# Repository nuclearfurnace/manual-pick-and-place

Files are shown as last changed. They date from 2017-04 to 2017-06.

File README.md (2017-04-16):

# manual-pick-and-place
A manual pick-and-place platform for DIY electronics, with an upgrade path.

## the goal
We want a solid pick and place table for manually placing components on prototypes and small runs.

DIY pick and place machines have successfully used off-the-shelf aluminum extrusions and linear guides/bearings to build rigid platforms that are suitable for precise work, even down to 0402 components.  There is a wide gulf, however, between manual set-ups and automatic/CNC machines.

Most manual setups involve tweezers or vacuum pens, which open up issues like gripping parts, dropping parts, dragging your hand across the board, etc. Even "advanced" manual setups are usually cobbled together, with parts you buy from a Home Depot or Lowes.

Our goal is to build a manual pick and place machine that has all the benefits of a CNC-enabled design -- modular, rigid, precise -- while staying simple enough to be usable by hand.  By using the same basic components as its CNC-enabled brethren, like aluminum extrusions and linear bearings, we can design a pick and place table that is capable of being upgraded to full auto in the future.

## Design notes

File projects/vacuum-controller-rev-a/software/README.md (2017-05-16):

Vacuum Controller software
--------------------------

This software powers the vacuum controller, controlling when the valves are opened/closed and for how long.  It's powered by an ATtiny85, so it's written in ANSI C targetting the Atmel AVR libraries.

We use simavr to simulate the firmware so we can write it without hardware in hand, and also more easily pin down behaviors without needing to trace an entire board.

how to use
----------

You should be able to run `make clean run` from this directory and have it just work.

You may or may not need to do something like:

    brew tap osx-cross/avr
    brew install --HEAD simavr

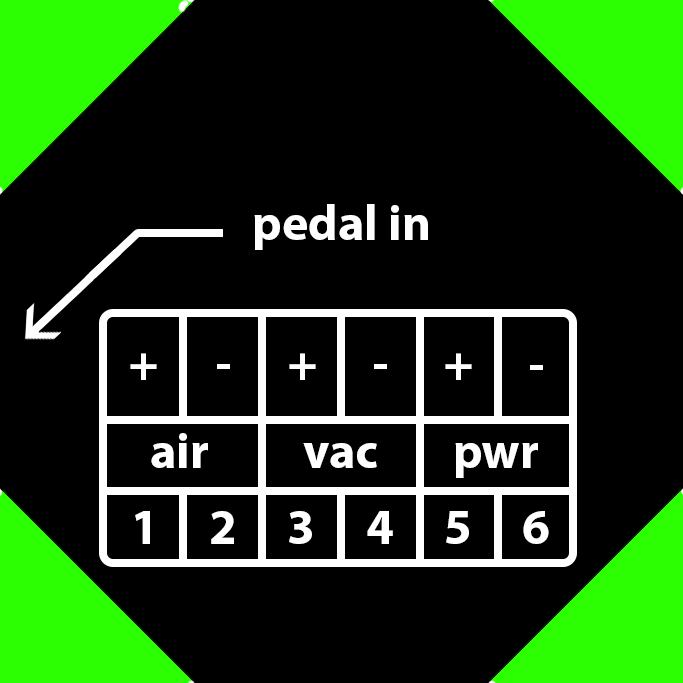
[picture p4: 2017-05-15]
projects/vacuum-controller-rev-a/graphics/vacuum-controller-panel.tif

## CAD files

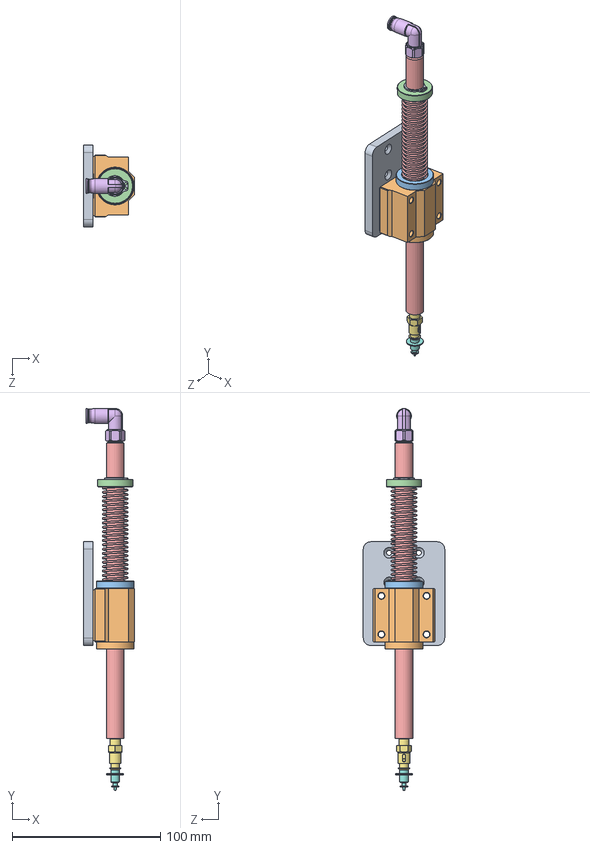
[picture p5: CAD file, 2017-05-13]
place-head-subassembly.SLDASM
34.3 x 257.8 x 55.0 mm
z-axis-bracket
LHBB12-1_b
LMU-N12
LH-RRING-C-INT-S-21 x 2
5964K110_HARDENED PRECISION TUBULAR METRIC SHAFT
RTCNL4-M5
cp40-nozzle-holder
cp40-test-nozzle
90967A165_STAINLESS STEEL EXTERNAL RETAINING RING x 2
nozzle-shaft-bottom-end-stop
nozzle-shaft-bottom-spring-holder
nozzle-shaft-top-spring-holder
9657K124_STEEL COMPRESSION SPRING

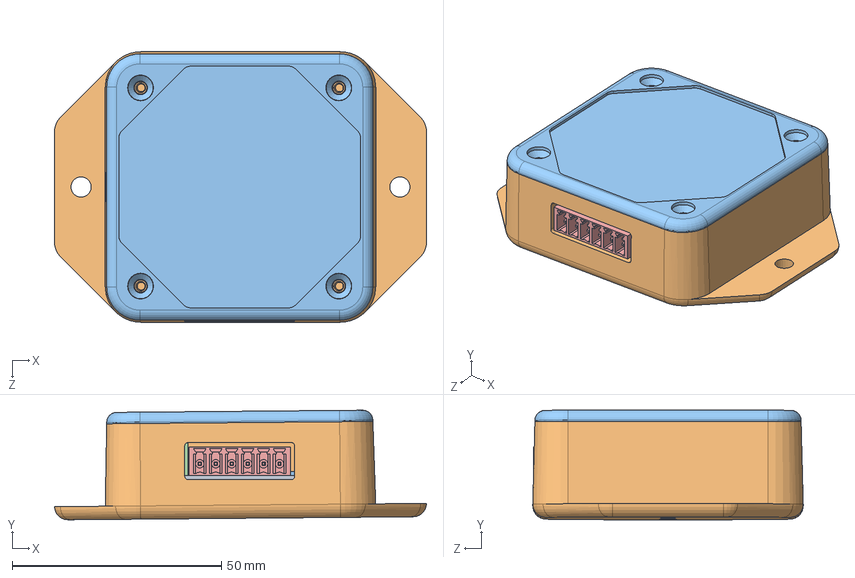
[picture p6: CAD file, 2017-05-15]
projects/vacuum-controller-rev-a/enclosure/vacuum-controller.SLDASM
88.9 x 26.2 x 64.6 mm
vacuumcontrollerreva
SOD323R_PMEG1020EA
SMA_13_6V
MJ-3536N
RPDSOG5DBV_LP5907MFX2_8
EIAJSOIC8_ATTINY8520SU
SOT457_SZNUD3124
RPDSOG5DCK_SN74AHC1G14DCK
LP-11F-bottom
LP-11F-cover

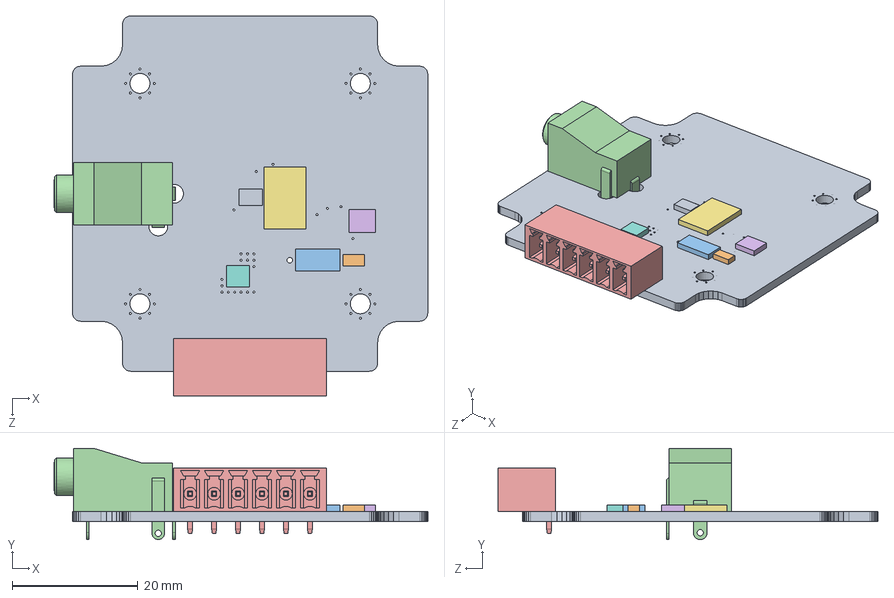
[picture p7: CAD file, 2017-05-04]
projects/vacuum-controller-rev-a/enclosure/components/vacuum-controller-board.SLDASM
59.4 x 14.5 x 60.4 mm
vacuumcontrollerreva
SOD323R_PMEG1020EA
SMA_13_6V
MJ-3536N
RPDSOG5DBV_LP5907MFX2_8
EIAJSOIC8_ATTINY8520SU
SOT457_SZNUD3124
RPDSOG5DCK_SN74AHC1G14DCK

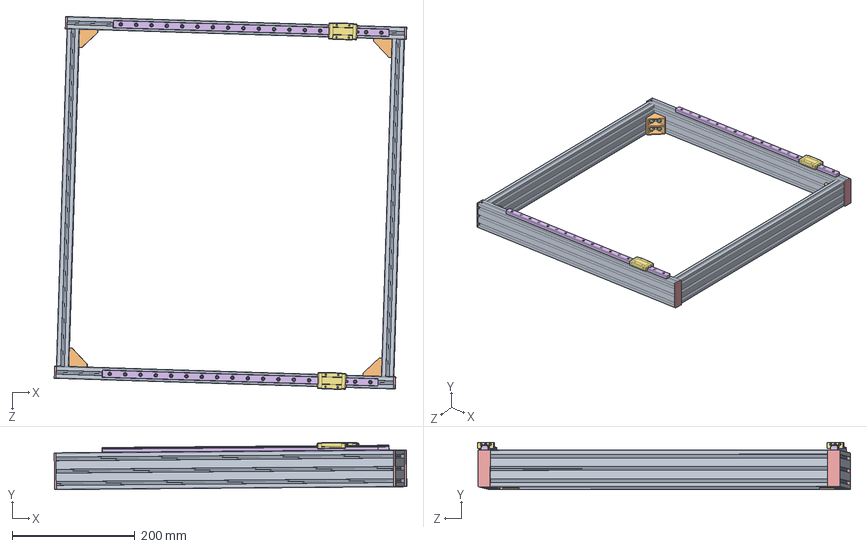
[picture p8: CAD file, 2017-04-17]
base-frame.SLDASM
574.8 x 77.0 x 608.0 mm
HFS5-2060-550 x 4
HBLFSN5h5 x 8
HNTT5-5 x 16
91292A124_TYPE 18-8 SS SOCKET HEAD CAP SCREW x 16
HFC5-2060-B x 4
MGN_12_H_RAIL x 2
MGN_12_H_CARRAGE x 2
HNTT5-3 x 20
91292A112_TYPE 18-8 SS SOCKET HEAD CAP SCREW x 20

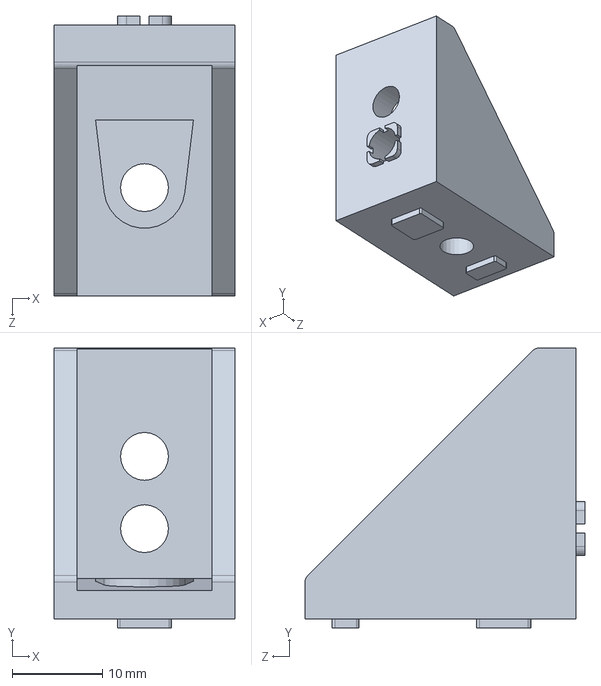
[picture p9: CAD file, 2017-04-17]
components/HBLFSN5.sldasm
20.0 x 31.0 x 31.0 mm

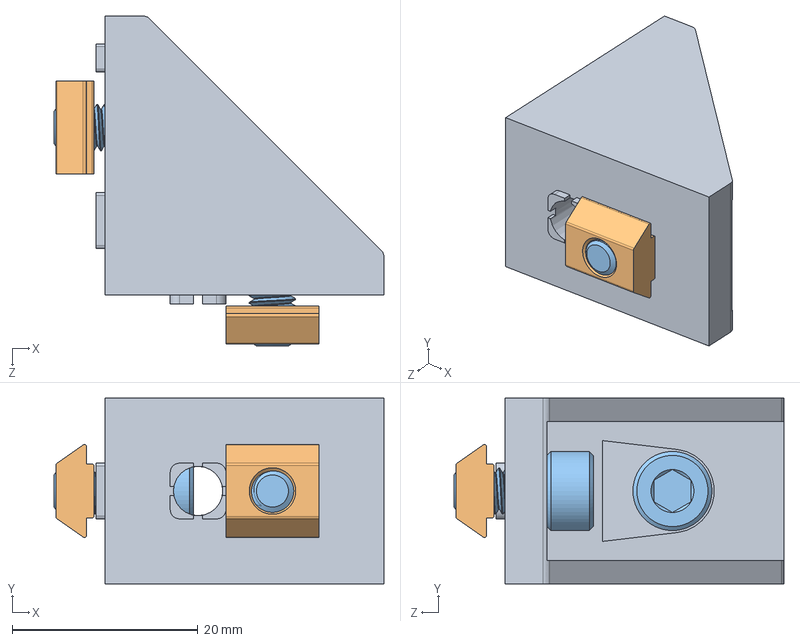
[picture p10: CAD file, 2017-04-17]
corner-bracket-w-hardware.SLDASM
35.5 x 20.0 x 35.5 mm
HBLFSN5h5
HNTT5-5 x 2
91292A124_TYPE 18-8 SS SOCKET HEAD CAP SCREW x 2

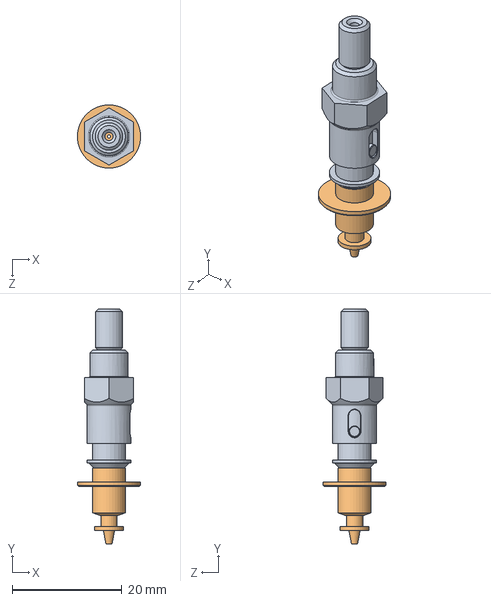
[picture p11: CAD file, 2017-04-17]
nozzle-assembly.SLDASM
11.5 x 42.8 x 11.5 mm
cp40-nozzle-holder
cp40-test-nozzle

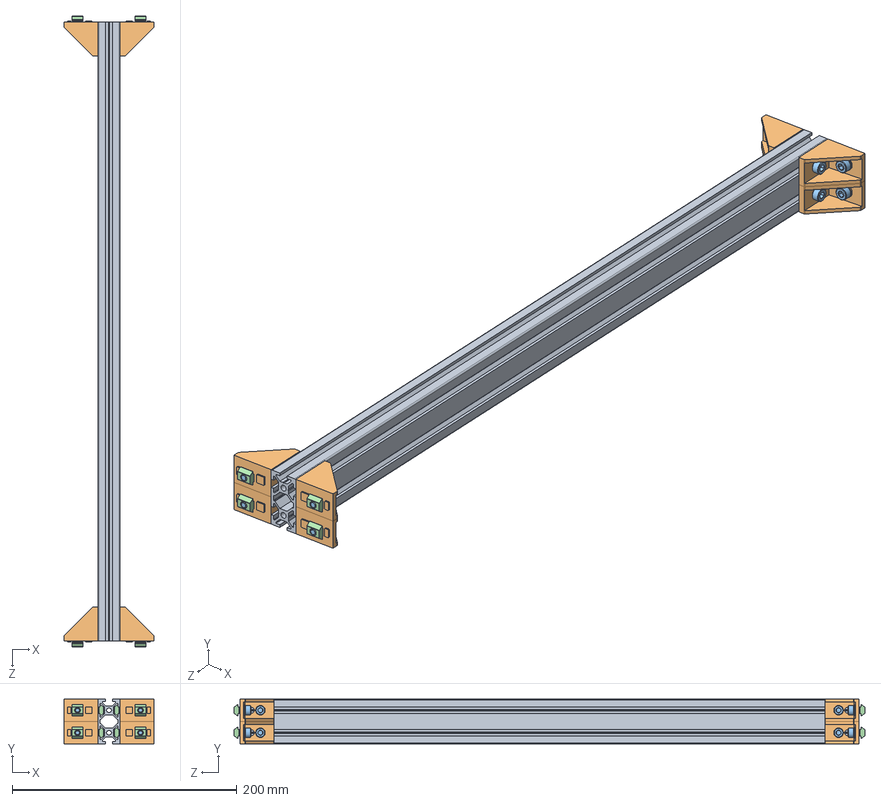
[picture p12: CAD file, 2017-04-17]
frame-stiffener.SLDASM
80.0 x 40.0 x 561.0 mm
HFS5-2040-550
HBLFSN5h5 x 8
91292A124_TYPE 18-8 SS SOCKET HEAD CAP SCREW x 16
HNTT5-5 x 16

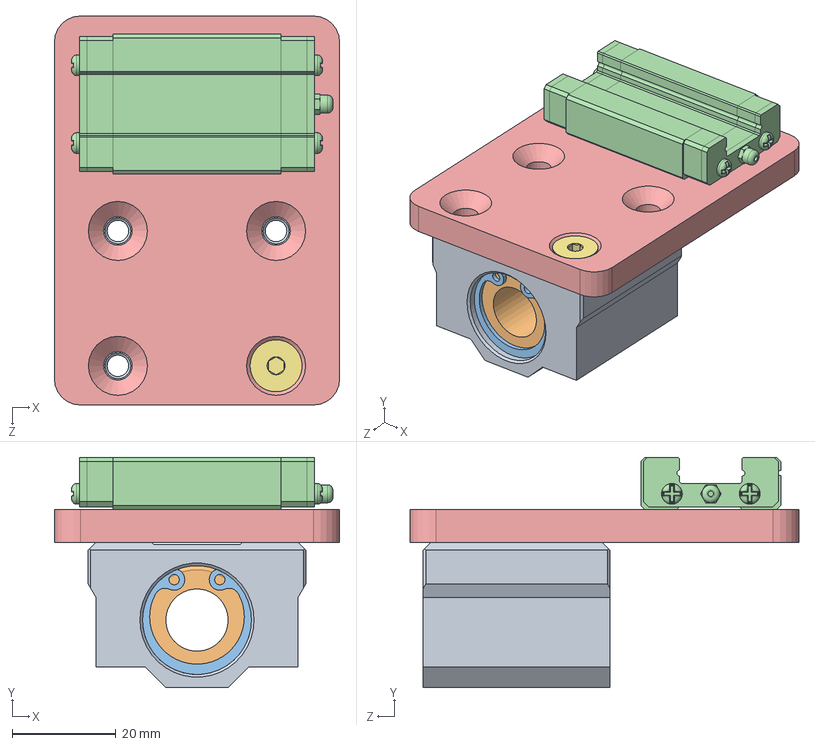
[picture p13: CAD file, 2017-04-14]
z-axis-assembly.SLDASM
55.0 x 44.3 x 75.0 mm
LHBB12-1_b
LMU-N12
LH-RRING-C-INT-S-21 x 2
MGN_12_H_CARRAGE
z-axis-bracket
92125A130_TYPE 18-8 SS FLAT-HEAD SOCKET CAP SCREW
92125A210_TYPE 18-8 SS FLAT-HEAD SOCKET CAP SCREW

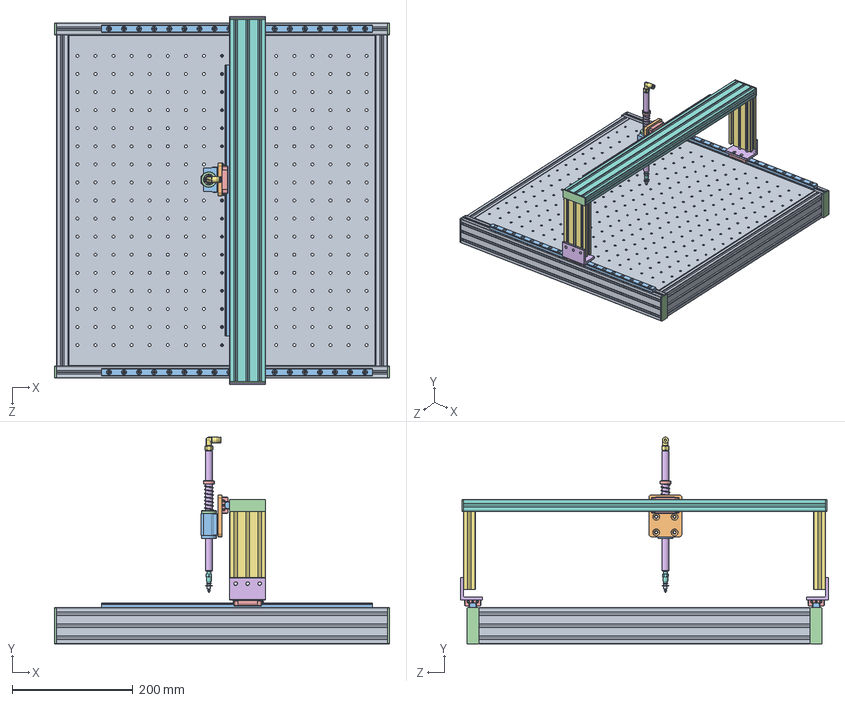
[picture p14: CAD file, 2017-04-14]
pick-and-place.SLDASM
556.0 x 343.2 x 611.3 mm
HFS5-2060-550 x 4
HFS5-2040-550 x 3
MGN_12_H_RAIL x 3
HFC5-2060-B x 6
MGN_12_H_CARRAGE x 3
x-axis-bracket x 2
HFS5-2060-130-Z5-YA10 x 2
HFS5-2060-600
place-bed
z-axis-bracket
LHBB12-1_b
LMU-N12
LH-RRING-C-INT-S-21 x 2
5964K110_HARDENED PRECISION TUBULAR METRIC SHAFT
RTCNL4-M5
CP40 nozzle holder
cp40-test-nozzle
90967A165_STAINLESS STEEL EXTERNAL RETAINING RING x 2
nozzle shaft bottom end stop
nozzle-shaft-bottom-spring-holder
nozzle-shaft-top-spring-holder
9657K396_STEEL COMPRESSION SPRING

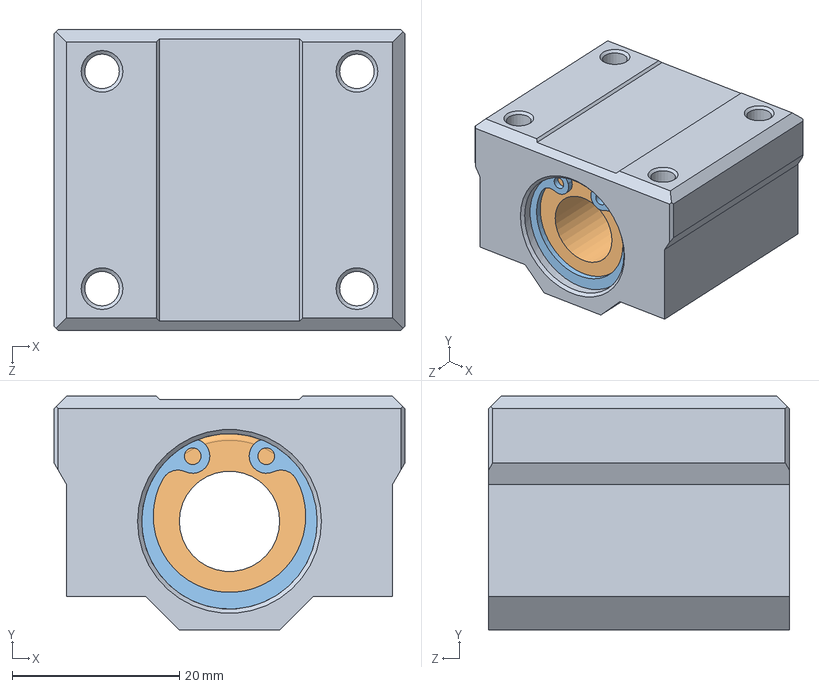
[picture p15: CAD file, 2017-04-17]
components/LHBB12.SLDASM
42.0 x 28.0 x 36.0 mm
LHBB12-1_b
LMU-N12
LH-RRING-C-INT-S-21 x 2

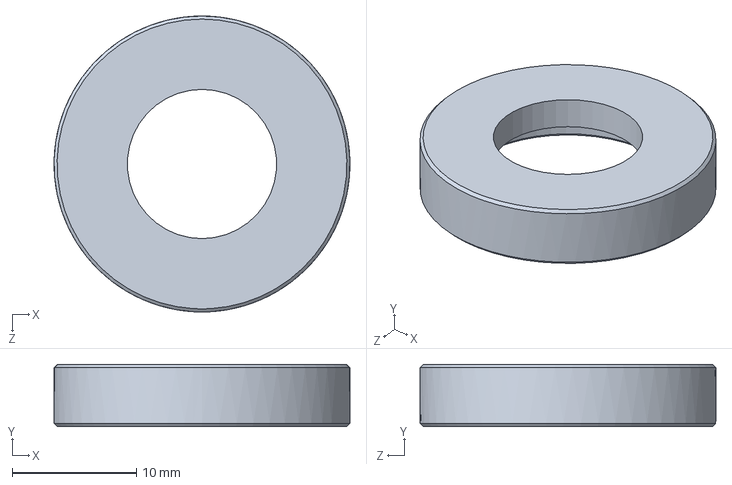
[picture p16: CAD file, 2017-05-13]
components/custom/nozzle-shaft-top-spring-holder.SLDPRT
23.8 x 5.00 x 23.8 mm

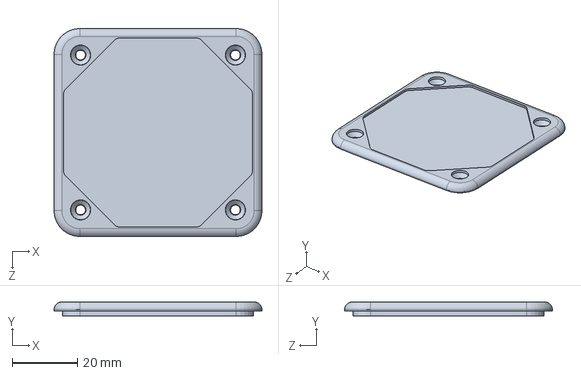
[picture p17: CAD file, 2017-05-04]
projects/vacuum-controller-rev-a/enclosure/components/LP-11F-cover.SLDPRT
63.6 x 4.32 x 63.6 mm

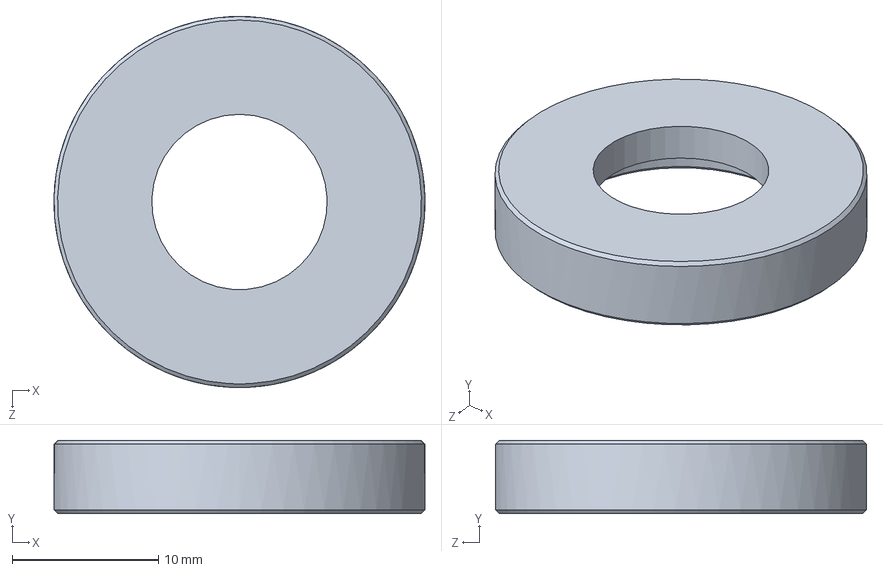
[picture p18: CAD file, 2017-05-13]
components/custom/nozzle-shaft-bottom-spring-holder.SLDPRT
25.4 x 5.00 x 25.4 mm

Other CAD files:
place-bed.SLDPRT
components/cp40-nozzle-holder.SLDPRT
components/custom/rail-end-stops.SLDPRT
projects/vacuum-controller-rev-a/enclosure/components/MJ-3536N.sldprt
components/5964K110_HARDENED PRECISION TUBULAR METRIC SHAFT.SLDPRT
components/90967A165_STAINLESS STEEL EXTERNAL RETAINING RING.SLDPRT
components/91292A112_TYPE 18-8 SS SOCKET HEAD CAP SCREW.SLDPRT
components/91292A124_TYPE 18-8 SS SOCKET HEAD CAP SCREW.SLDPRT
components/91292A129_TYPE 18-8 SS SOCKET HEAD CAP SCREW.SLDPRT
components/92125A128_TYPE 18-8 SS FLAT-HEAD SOCKET CAP SCREW.SLDPRT
components/92125A130_TYPE 18-8 SS FLAT-HEAD SOCKET CAP SCREW.SLDPRT
components/92125A210_TYPE 18-8 SS FLAT-HEAD SOCKET CAP SCREW.SLDPRT
components/93475A240_TYPE 18-8 STAINLESS STEEL FLAT WASHER.SLDPRT
components/9657K124_STEEL COMPRESSION SPRING.SLDPRT
components/HBLFSN5h5.sldprt
components/HFC5-2060-B.sldprt
components/HFS5-2040-550.sldprt
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

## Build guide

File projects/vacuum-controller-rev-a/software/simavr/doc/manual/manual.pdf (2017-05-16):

# simavr Manual

## Jakob Gruber jakob.gruber@gmail.com

## 26. Juli 2015

# Contents

1. Introduction | 1
2. simavr Internals | 2
A. Setup Guide | 27

i

# 1. Introduction

This manual is an excerpt of the bachelor’s thesis “qsimavr: Graphical Simulation of an AVR Processor and Periphery” by Jakob Gruber. The full thesis is available at https://github.com/schuay/bachelors_thesis.

Chapter 2 provides a brief overview of simavr internals, followed by a setup guide in appendix A.

# 2. simavr Internals

simavr is a small cross-platform Alf and Vegard’s Risc processor (AVR) simulator written with simplicity, efficiency and hackability in mind¹
. It is supported
on Linux and OS X, but should run on any platform with avr-libc support. In the following sections, we will take a tour through simavr internals² . We
will begin by examining short (but complete) demonstration application.

## 2.1. simavr Example Walkthrough

The following program is taken from the board i2ctest simavr example. Minor modifications have been made to focus on the essential section. Error handling is mostly omitted in favor of readability.

# include < stdlib .h >

# include < stdio .h >

# include < libgen .h >

# include < pthread .h >

# include " sim_avr . h "

# include " avr_twi . h "

# include " sim_elf . h "

# include " sim_gdb . h "

# include " sim_vcd_file . h "

# include " i2c_eeprom . h"

The actual simulation of the external Electrically Erasable Programmable Read-Only Memory (EEPROM) component is located in i2c eeprom.h. We will take a look at the implementation later on.

avr_t * avr = NULL ;
avr_vcd_t vcd_file ;

i2c_eeprom_t ee ;

1 For some more technical principles, simavr also tries to avoid heap allocation at runtime and often relies on C99’s struct set initialization.
2 Most, if not all of the code examined in this chapter is taken directly from simavr .

2.1 simavr Example Walkthrough | 2 simavr Internals

avr is the main data structure. It encapsulates the entire state of the core simulation, including register, Static Random-Access Memory (SRAM) and flash contents, the Central Processing Unit (CPU) state, the current cycle count, callbacks for various tasks, pending interrupts, and more.

vcd_file represents the file target for the Value Change Dump (VCD) module. It is used to dump the level changes of desired pins (or Interrupt Requests (IRQs) in general) into a file which can be subsequently viewed using utilities such as gtkwave.

ee contains the internal state of the simulated external EEPROM.

int main ( int argc , char * argv [])
{
elf_firmware_t f ;
elf_read_firmware ( " atmega1280_i2ctest . axf " , & f) ;

The firmware is loaded from the specified file. Note that exactly the same file can be executed on the AVR hardware without changes. Microcontroller (MCU) and frequency information have been embedded into the binary and are therefore available in elf_firmware_t.

avr = avr_make_mcu_by_name ( f . mmcu ) ;
avr_init ( avr ) ;
avr_load_firmware ( avr , & f) ;

The avr_t instance is then constructed from the core file of the specified MCU and initialized. avr_load_firmware copies the firmware into program memory.

i2c_eeprom_init ( avr , & ee , 0 xa0 , 0 xfe , NULL , 1024) ; i2c_eeprom_attach ( avr , & ee , AVR_IOCTL_TWI_GETIRQ
(0) ) ;

AVR_IOCTL_TWI_GETIRQ is a macro to retrieve the internal IRQ of the Two-Wire Interface (TWI) simulation. IRQs are the main method of communication between simavr and external components and are also used liberally throughout simavr internals. Similar macros exist for other important AVR parts such as the Analog-Digital Converter (ADC), Input/Output (IO) ports, timers, etc.

avr - > gdb_port = 1234;
avr - > state = cpu_Stopped ;
avr_gdb_init ( avr ) ;

This section sets up simavr ’s GNU Debugger (GDB) infrastructure to listen on port 1234. The CPU is stopped to allow GDB to attach before execution begins.

2.1 simavr Example Walkthrough | 2 simavr Internals

avr_vcd_init ( avr , " gtkwave_output . vcd " , & vcd_file , 100000 /* usec */) ;
avr_vcd_add_signal (
& vcd_file ,
avr_io_getirq ( avr , AVR_IOCTL_TWI_GETIRQ (0) , TWI_IRQ_STATUS ) ,
8 /* bits */ ,
" TWSR ") ;

Next, a value change dump output is configured to track changes to the TWI_IRQ_STATUS IRQ. The file may then be viewed using the gtkwave application.

int state = cpu_Running ;
while (( state != cpu_Done ) && ( state != cpu_Crashed ) )
state = avr_run ( avr ) ;

return 0;
}

Finally, we have reached the simple main loop. Each iteration executes one instruction, handles any pending interrupts and cycle timers, and sleeps if possible. As soon as execution completes or crashes, simulation stops and we exit the program.

We will now examine the relevant parts of the i2c_eeprom implementation. Details have been omitted and only communication with the avr_t instance are shown.

static const char * _ee_irq_names [2] = {
[ TWI_IRQ_MISO ] = "8 > eeprom . out " , [ TWI_IRQ_MOSI ] = " 32 < eeprom . in " , };

void
i2c_eeprom_init (
struct avr_t * avr ,
i2c_eeprom_t * p ,
uint8_t addr ,
uint8_t mask ,
uint8_t * data ,
size_t size )
{

2.1 simavr Example Walkthrough | 2 simavr Internals

/* [...] */

p - > irq = avr_alloc_irq (& avr - > irq_pool , 0 , 2, _ee_irq_names ) ;
avr_irq_register_notify (p - > irq + TWI_IRQ_MOSI , i2c_eeprom_in_hook , p ) ;

/* [...] */
}

First, the EEPROM allocates its own private IRQs. The EEPROM implementation does not know or care to which simavr IRQs they will be attached. It then attaches a callback function (i2c_eeprom_in_hook) to the Master Out, Slave In (MOSI) IRQ. This function will be called whenever a value is written to the IRQ. The pointer to the EEPROM state p is passed to each of these callback function calls.

void
i2c_eeprom_attach (
struct avr_t * avr ,
i2c_eeprom_t * p ,
uint32_t i2c_irq_base )
{
avr_connect_irq (
p - > irq + TWI_IRQ_MISO , avr_io_getirq ( avr , i2c_irq_base , TWI_IRQ_MISO ) ) ;
avr_connect_irq (
avr_io_getirq ( avr , i2c_irq_base , TWI_IRQ_MOSI ) ,
p - > irq + TWI_IRQ_MOSI ) ;
}

The private IRQs are then attached to simavr ’s internal IRQs. This is called chaining - all messages raised are forwarded to all chained IRQs.

static void
i2c_eeprom_in_hook (
struct avr_irq_t * irq ,
uint32_t value ,
void * param )
{
i2c_eeprom_t * p = ( i2c_eeprom_t *) param ;

2.2 The Main Loop | 2 simavr Internals

/* [...] */

avr_raise_irq (p - > irq + TWI_IRQ_MISO , avr_twi_irq_msg ( TWI_COND_ACK , p -> selected ,
1) ) ;

/* [...] */
}

Finally, we’ve reached the IRQ callback function. It is responsible for simulating communications between simavr (acting as the TWI master) and the EEPROM (as the TWI slave). The EEPROM state which was previously passed to avr_irq_register_notify is contained in the param variable and cast back to an i2c_eeprom_t pointer for further use.

Outgoing messages are sent by raising the internal IRQ. This message is then forwarded to all chained IRQs.

## 2.2. The Main Loop

We will now take a closer look at the main loop implementation. Each call to avr_run triggers the function stored in the run member of the avr_t structure (avr->run³
). The two standard implementations are avr_callback_run_raw and avr_callback_run_gdb, located in sim avr.c. The essence of both function is identical; since avr_callback_run_gdb contains additional logic for GDB handling (network protocol, stepping), we will examine it further and point out any differences to the the raw version. Several comments and irrelevant code sections have been removed.

void avr_callback_run_gdb ( avr_t * avr )
{
avr_gdb_processor ( avr , avr - > state == cpu_Stopped ) ;

if ( avr - > state == cpu_Stopped )
return ;

int step = avr - > state == cpu_Step ; if ( step )
avr - > state = cpu_Running ;

3Whenever avr is mentioned in a code section, it is assumed to be the main avr_t struct.

2.2 The Main Loop | 2 simavr Internals

This initial section is GDB specific. avr_gdb_processor is responsible for handling GDB network communication. It also checks if execution has reached a breakpoint or the end of a step and stops the CPU if it did.

If GDB has transmitted a step command, we need to save the state during the main section of the loop (the CPU “runs” for one instruction) and restore to the StepDone state at on completion.

In total, there are eight different states the CPU can enter:

enum {
cpu_Limbo = 0 ,
cpu_Stopped ,
cpu_Running ,
cpu_Sleeping ,
cpu_Step ,
cpu_StepDone ,
cpu_Done ,
cpu_Crashed ,
};

A CPU is Running during normal execution. Stopped occurs for example when hitting a GDB breakpoint. Sleeping is entered whenever the SLEEP instruction is processed. As mentioned, Step and StepDone are related to the GDB stepping process. Execution can terminate either with Done or Crashed on error. Upon initialization, the CPU is in the Limbo state.

avr_flashaddr_t new_pc = avr - > pc ;

if ( avr - > state == cpu_Running ) { new_pc = avr_run_one ( avr ) ;
}

We have now reached the actual execution of the current instruction. If the CPU is currently running, avr_run_one decodes the instruction located in flash memory (avr->flash) and triggers all necessary actions. This can include setting the CPU state (SLEEP), updating the status register Status Register (SREG), writing or reading from memory locations, altering the Program Counter (PC), etc . . .

Finally, the cycle counter (avr->cycle) is updated and the new program counter is returned.

if ( avr - > sreg [ S_I ] && ! avr - > i_shadow )
avr - > interrupts . pending_wait ++; avr - > i_shadow = avr - > sreg [ S_I ];

2.2 The Main Loop | 2 simavr Internals

This section ensures that interrupts are not triggered immediately when enabling the interrupt flag in the status register, but with an (additional) delay of one instruction.

avr_cycle_count_t sleep = avr_cycle_timer_process ( avr ) ;
avr - > pc = new_pc ;

Next, all due cycle timers are processed. Cycle timers are one of the most important and heavily used mechanisms in simavr . A timer allows scheduling execution of a callback function once a specific count of execution cycles have passed, thus simulating events which occur after a specific amount of time has passed. For example, the avr_timer module uses cycle timers to schedule timer interrupts.

The returned estimated sleep time is set to the next pending event cycle (or a hardcoded limit of 1000 cycles if none exist).

if ( avr - > state == cpu_Sleeping ) {
if (! avr - > sreg [ S_I ]) {
avr - > state = cpu_Done ; return ;
}
avr - > sleep ( avr , sleep ) ; avr - > cycle += 1 + sleep ; }

If the CPU is currently sleeping, the time spent is simulated using the callback stored in avr->sleep. In GDB mode, the time is used to listen for GDB commands, while the raw version simply calls usleep.

It is worth noting that we have improved the timing behavior by accumulating requested sleep cycles until a minimum of 200 usec has been reached. usleep cannot handle lower sleep times accurately, which caused an unrealistic execution slowdown.

A special case occurs when the CPU is sleeping while interrupts are turned off. In this scenario, there is no way of ever waking up. Therefore, execution is halted gracefully.

if ( avr - > state == cpu_Running || avr - > state == cpu_Sleeping )
avr_service_interrupts ( avr );

Finally, any immediately pending interrupts are handled. The highest priority interrupt (this depends solely on the interrupt vector address) is removed

2.3 Initialization | 2 simavr Internals

from the pending queue, interrupts are disabled in the status register, and the program counter is set to the interrupt vector.

If the CPU is sleeping, interrupts can be raised by cycle timers.

if ( step )
avr - > state = cpu_StepDone ; }

Wrapping up, if the current loop iteration was a GDB step, the state is set such that the next iteration will inform GDB and halt the CPU.

## 2.3. Initialization

### 2.3.1. avr_t Initialization

The avr_t struct requires some initialization before it is ready to be used by the main loop as discussed in section 2.2.

avr_make_mcu_by_name fills in all details specific to an MCU. This includes settings such as memory sizes, register locations, available components, the default CPU frequency, etc . . .

The MCU definitions are located in the simavr/cores subdirectory of the simavr source tree and are compiled conditionally depending on the the local avr-libc support. A complete list of locally supported cores is printed by running simavr without any arguments.

On successful completion, it returns a pointer to the avr_t struct.

If GDB support is desired, avr->gdb_port must be set, and avr_gdb_init must be called to create the required data structures, set the avr->run and avr->sleep callbacks, and listen on the specified port. It is also recommended to initially stop the cpu (avr->state = cpu_Stopped) to delay program execution until it is started manually by GDB.

Further settings can now be applied manually (typical candidates are logging and tracing levels).

### 2.3.2. Firmware

We now have a fully initialized avr_t struct and are ready to load code. This is accomplished using avr_read_firmware, which uses elfutils to decode the Executable and Linkable Format (ELF) file and read it into an elf_firmware_t struct and avr_load_firmware to load its contents into the avr_t struct.

2.3 Initialization | 2 simavr Internals

Besides loading the program code into avr->flash (and EEPROM contents into avr->eeprom, if available), there are several useful extended features which can be embedded directly into the ELF file.

The target MCU, frequency and voltages can be specified in the ELF file by using the AVR_MCU and AVR_MCU_VOLTAGES macros provided by avr_mcu_section.h:

# include " avr_mcu_section . h "

AVR_MCU (16000000 /* Hz */ , " atmega1280 " ) ; AVR_MCU_VOLTAGES (3300 /* milliVolt */ , 3300 /* milliVolt */ , 3300 /* milliVolt */) ;

VCD traces can be set up automatically. The following code will create an 8-bit trace on the UDR0 register, and a trace masked to display only the UDRE0 bit of the UCSR0A register.

const struct avr_mmcu_vcd_trace_t _mytrace [] _MMCU_ = {
{ AVR_MCU_VCD_SYMBOL ( " UDR0 " ) , . what = ( void *) & UDR0 , } ,
{ AVR_MCU_VCD_SYMBOL ( " UDRE0 " ) , . mask = (1 << UDRE0 ) , . what = ( void *) & UCSR0A , } ,
};

Several predefined commands can be sent from the firmware to simavr during program execution. At the time of writing, these include starting and stopping VCD traces, and putting UART0 into loopback mode. An otherwise unused register must be specified to listen for command requests. During execution, writing a command to this register will trigger the associated action within simavr .

AVR_MCU_SIMAVR_COMMAND (& GPIOR0 ) ;

int main () {
/* [...] */
GPIOR0 = SIMAVR_CMD_VCD_START_TRACE ; /* [...] */
}

Likewise, a register can be specified for use as a debugging output. All bytes written to this register will be output to the console.

AVR_MCU_SIMAVR_CONSOLE (& GPIOR0 ) ;

int main () {

2.4 Instruction Processing | 2 simavr Internals

/* [...] */
const char * s = " Hello World \ r " ; for ( const char *t = s ; *t ; t ++) GPIOR0 = * t;
/* [...] */
}

Usually, UART0 is used for this purpose. The simplest debug output can be achieved by binding stdout to UART0 as described by the avr-libc documentation [?], and then using printf and similar functions. This alternate console output is provided in case using UART0 is not possible or desired.

## 2.4. Instruction Processing

We have now covered avr_t initialization, the main loop, and loading firmware files. But how are instructions actually decoded and executed? Let’s take a look at avr_run_one, located in sim core.

The opcode is reconstructed by retrieving the two bytes located at avr-> flash[avr->pc]. avr->pc points to the Least Significant Byte (LSB), and avr->pc + 1 to the Most Significant Byte (MSB). Thus, the full opcode is reconstructed with:

uint32_t opcode = ( avr - > flash [ avr - > pc + 1] << 8) | avr
- > flash [ avr - > pc ];

As we have seen, avr->pc represents the byte address in flash memory. Therefore, the next instruction is located at avr->pc + 2. This default new program counter may still be altered in the course of processing in case of jumps, branches, calls and larger opcodes such as STS[?].

Note also that the AVR flash addresses are usually represented as word addresses (avr->pc >> 1).

Similar to the program counter, the spent cycles are set to a default value of 1.

The instruction and its operands are then extracted from the opcode and processed in a large switch statement. The instructions themselves can be roughly categorized into arithmetic and logic instructions, branch instructions, data transfer instructions, bit and bit-test instructions, and MCU control instructions.

Processing these will involve a number of typical tasks:

2.5 Interrupts | 2 simavr Internals
- Status register modifications

The status register is stored in avr->sreg as a byte array. Most instructions alter the SREG in some way, and convenience functions such as get_compare_carry are used to ease this task. Note that whenever the firmware reads from SREG, it must be reconstructed from avr->sreg.

- Reading or writing memory

_avr_set_ram is used to write bytes to a specific address. Accessing an SREG will trigger a reconstruction similar to what has been discussed above. IO register accesses trigger any connected IO callbacks and raise all associated IRQs. If a GDB watchpoint has been hit, the CPU is stopped and a status report is sent to GDB. Data watchpoint support has been added by the author.

- Modifying the program counter

Jumps, skips, calls, returns and similar instructions alter the program counter. This is achieved by simply setting new_pc to an appropriate value. Care must be taken to skip 32 bit instructions correctly.

- Altering MCU state

Instructions such as SLEEP and BREAK directly alter the state of the simulation.

- Stack operations

Pushing and popping the stack involve altering the stack pointer in addition to the actual memory access.

Upon conclusion, avr->cycle is updated with the actual instruction duration, and the new program counter is returned.

## 2.5. Interrupts

An interrupt is an asynchronous signal which causes the the CPU to jump to the associated Interrupt Service Routine (ISR) and continue execution there. In the AVR architecture, the interrupt priority is ordered according to its place in the interrupt vector table. When an interrupt is serviced, interrupts are disabled globally.

### 2.5.1. Data Structures

Let’s take a look at how interrupts are represented in simavr :

2.5 Interrupts | 2 simavr Internals

typedef struct avr_int_vector_t {
uint8_t | vector ;
avr_regbit_t | enable ;
avr_regbit_t | raised ;
avr_irq_t | irq ;
uint8_t | pending : 1 ,
| trace : 1 ,
| raise_sticky : 1;
} avr_int_vector_t ;

Each interrupt vector has an avr_int_vector_t. vector is actual vector address, for example INT0_vect. enable and raised specify the IO register index for, respectively, the interrupt enable flag and the interrupt raised bit (again taking INT0 as an example, enable would point to the INT0 bit in EIMSK , and raised to INTF0 in EIFR. irq is raised to 1 when the interrupt is triggered, and to 0 when it is serviced. pending equals 1 whenever the interrupt is queued for servicing, and trace is used for debugging purposes.
Usually, raised flags are cleared automatically upon interrupt servicing. However, this does not count for all interrupts(notably, TWINT). raise_sticky was introduced by the author to handle this special case.
Interrupt vector definitions are stored in an avr_int_table_t, avr-> interrupts.

typedef struct avr_int_table_t {
avr_int_vector_t * vector [64];
uint8_t | vector_count ;
uint8_t | pending_wait ;
avr_int_vector_t * pending [64];
uint8_t | pending_w ,
| pending_r ;
} avr_int_table_t , * avr_int_table_p ;

pending_wait stores the number of cycles to wait before servicing pending interrupts. This simulates the real interrupt delay that occurs between raising and servicing, and whenever interrupts are enabled (and previously disabled). pending along with pending_w and pending_r represents a ringbuffer of pending interrupts. Note that servicing an interrupt removes the one with the highest priority.

### 2.5.2. Raising and Servicing Interrupts

When an interrupt vector is raised, vector->pending is set, vector is added to the pending First In, First Out (FIFO) of avr->interrupts, and a non-zero

2.6 Cycle Timers | 2 simavr Internals

pending_wait time is ensured. If the CPU is currently sleeping, it is woken up.

As we’ve already covered in section 2.2, servicing interrupts is only attempted if the CPU is either running or sleeping. Additionally, interrupts must be enabled globally in SREG, and pending_wait (which is decremented on each avr_service_interrupts call) must have reached zero. The next pending vector with highest priority is then removed from the pending ringbuffer and serviced as follows:

if (! avr_regbit_get ( avr , vector - > enable ) || ! vector - > pending ) {
vector - > pending = 0;

If the specific interrupt is masked or has been cleared, no action occurs.

} else {
_avr_push16 ( avr , avr - > pc >> 1) ;
avr - > sreg [ S_I ] = 0;
avr - > pc = vector - > vector * avr - > vector_size ; avr_clear_interrupt ( avr , vector ) ;
}

Otherwise, the current program counter is pushed onto the stack. This illustrates the difference between byte addresses (as used in avr->pc) and word addresses (as expected by the AVR processor). Interrupts are then disabled by clearing the I bit of the status register, and the program counter is set to the ISR vector. Finally, if raise_sticky is 0, the interrupt flag is cleared.

## 2.6. Cycle Timers

Cycle timers allow scheduling an event after a certain amount of cycles have passed.

typedef avr_cycle_count_t (* avr_cycle_timer_t ) ( struct avr_t * avr ,
avr_cycle_count_t when ,
void * param ) ;

void
avr_cycle_timer_register ( struct avr_t * avr ,
avr_cycle_count_t when ,
avr_cycle_timer_t timer ,

2.7 GNU Debugger (GDB) Support | 2 simavr Internals

void * param ) ;

In avr_cycle_timer_register, when is the minimum count of cycles that must pass until the timer callback is executed (param and when are passed back to timer⁴
).

Once dispatched, the cycle timer is removed from the list of pending timers. If it returns a nonzero value, it is readded to occur at or after that cycle has been reached. It is important to realize that it therefore differs from the when argument of avr_cycle_timer_register, which expects a relative cycle count (in contrast to the absolute cycle count returned by the callback itself)⁵

The cycle timer system is used during the main loop to determine sleep durations; if there are any pending timers, the sleep callback may sleep until the next timer is scheduled. Otherwise, a default value of 1000 cycles is returned. Besides achieving a runtime behavior similar to execution on a real AVR processor, sleep is important for lowering simavr CPU usage whenever possible.

IRQs and interrupts caused by external events (for example, a “touch” event transmitted from the simulated touchscreen component) are and can not be taken into account. This means that scheduled sleep times will always be simulated to completion by avr->sleep, even if an external event causing CPU wakeup is triggered immediately after going to sleep. Given a situation in which the next scheduled timer is many cycles in the future and the CPU is currently sleeping, the simulation will become extremely unresponsive to external events.

However, in real applications this situation is very unlikely, since manual events (which cannot be scheduled through cycle timers) occur very rarely, and most applications will have at least some cycle timers with a short period.

It is worth remembering though, that cycle timers are the preferred and most accurate method of scheduling interrupts in simavr .

## 2.7. GNU Debugger (GDB) Support

A debugger is incredibly useful during program development. Simple programming mistakes which can be discovered in minutes using GDB can sometimes consume hours to find without it.

4
qsimavr exploits param to implement callbacks to class instances by passing the this pointer as param.
5 Treating the return value of avr_cycle_timer_t as an absolute value and passing the actually scheduled cycle allows for precise handling of recurring timers without drift. A system based on relative cycle counts could not guarantee accuracy, because simavr does not guarantee cycle timer execution exactly at the scheduled point in time.

2.7 GNU Debugger (GDB) Support | 2 simavr Internals

We have covered how to enable GDB support in section 2.3.1, and when GDB handler functions are called during the main loop in section 2.2. In the following, we will explain further the methods simavr employs to communicate with GDB and how breakpoints and data watchpoints are implemented. For a short guide to debugging AVR programs with GDB, see section ??

simavr has a fully featured implementation of the GDB Remote Serial Protocol, which allows it to communicate with avr-gdb. A complete reference of the protocol can be obtained from the GDB manual [?]. Essentially, communication boils down to packets of the format $packet-data#checksum. The packet data itself consists of a command and its arguments. The syntax of all commands supported by simavr is as follows:

’?’ Indicate the reason the target halted.
’G XX...’ Write general registers.
’g’ Read general registers.
’p n’ Read the value of register n.
’P n...=r...’ Write register n with value r.
’m addr,length’ Read length bytes of memory starting at address addr.
’M addr,length:XX...’ Write length bytes of memory starting address addr. XX... is the data. ’c’ Continue.
’s’ Step.
’r’ Reset the entire system.
’z type,addr,kind’ Delete break and watchpoints.
’Z type,addr,kind’ Insert break and watchpoints.

Many of these commands expect a reply value. This could be a simple as sending "OK" to confirm successful execution, or it could contain the requested data, such as the reply to the ’m’ command. A single reply can chain several data fields. For example, whenever a watchpoint is hit, the reply contains the signal the program received (0x05 represents the “trap” signal), the SREG, Stack Pointer (SP), and PC values, the type of watchpoint which was hit (either "awatch", "watch", or "rwatch"), and the watchpoint address.

The packets themselves are received and sent over an AF_INET socket listening on the avr->gdb_port.

Both | watchpoints | and | breakpoints | are | stored | within | an
avr_gdb_watchpoints_t struct in avr->gdb and are limited to 32 active instances of each. Breakpoints are set at a particular location in flash memory. Whenever the PC reaches that that point, execution is halted, a status report containing a summary of current register values is sent, and control is passed to GDB. This range check takes place in avr_gdb_processor, which

2.8 Interrupt Requests (IRQs) | 2 simavr Internals

is called first during each iteration of the avr_callback_run_gdb function as we have already discussed in section 2.2.
Watchpoints⁶ on the other hand are used to notify the user of accesses to SRAM. GDB uses a fixed offset of 0x800000 to reference locations in SRAM; this offset must be masked out when receiving GDB commands, and added when sending watchpoint status reports. Three types of watchpoints exist: Read watchpoints are triggered by data reads, write watchpoints by writes, and access watchpoints by both. Handling of these is integrated into the avr_core_watch_write and avr_core_watch_read functions. Whenever applicable watchpoints exist for a data access, execution is halted, and a status report is sent to GDB.

Finally, since program crashes often occur unexpectedly, simavr helpfully provides GDB passive mode, which opens a GDB listening socket whenever an exception occurs if the GDB port is specified. It is therefore always a good idea to initialize avr->gdb_port, even if you have no intention of using simavr ’s GDB features!

## 2.8. Interrupt Requests (IRQs)

The Interrupt Request (IRQ)⁷
subsystem provides the message passing mechanism in simavr . Let’s begin by examining the main IRQ data structures:

typedef struct avr_irq_t {
struct avr_irq_pool_t * pool ;
const char * name ;
uint32_t | irq ;
uint32_t | value ;
uint8_t | flags ;
struct avr_irq_hook_t * hook ;
} avr_irq_t ;

An IRQ consists of an associated IRQ pool, a name (for debugging purposes), an Identifier (ID), its current value, flags, and a list of callback functions. The ID (irq) is when a callback function connected to several IRQs needs to determine which specific IRQ has been raised.

The semantics of value are not fixed and are specific to each IRQ; for example, ADC_IRQ_ADC0 treats value as milliVolts, while IOPORT_IRQ_PIN0 expects

6Watchpoint support has been added by the author.
7 Despite the name, IRQs have nothing in particular to do with interrupts; the interrupt system uses IRQs, and IRQs may trigger interrupts, but they are not strictly linked to each other. Many IRQ usages will not involve interrupts at all.

2.8 Interrupt Requests (IRQs) | 2 simavr Internals

it to equal either 1 (high) or 0 (low). flags is a bitmask of several options⁸ .
IRQ_FLAG_NOT flips the polarity of the signal (raising an IRQ with value 1 results in a value of 0 and vice versa). Setting IRQ_FLAG_FILTERED instructs simavr to ignore IRQ raises with unchanged values.

hook contains a linked list of chained IRQs and avr_irq_notify_t callbacks.

typedef void (* avr_irq_notify_t ) (
struct avr_irq_t * irq ,
uint32_t value ,
void * param ) ;

void
avr_irq_register_notify (
avr_irq_t * irq ,
avr_irq_notify_t notify ,
void * param ) ;

Callbacks are executed whenever an IRQ is raised (and is not filtered). Chained IRQs are raised whenever the IRQ they are connected to is raised.

As briefly mentioned in section 2.1, module implementations usually structure communication with the simavr core by allocating their own private IRQs, which are then connected to the target simavr IRQs. Callbacks are registered on private IRQs; likewise, only private IRQs are raised. This ensures maximum flexibility since IRQ connections are defined in one single location. Relevant functions are:

avr_irq_t *
avr_alloc_irq (
avr_irq_pool_t * pool ,
uint32_t base ,
uint32_t count ,
const char ** names /* optional */) ;

void
avr_irq_register_notify (
avr_irq_t * irq ,
avr_irq_notify_t notify ,
void * param ) ;

void

8 IRQ_FLAG_ALLOC and IRQ_FLAG_INIT are of internal interest only and not mentioned further.

2.9 Input/Output (IO) | 2 simavr Internals

avr_connect_irq (
avr_irq_t * src ,
avr_irq_t * dst ) ;

void
avr_raise_irq (
avr_irq_t * irq ,
uint32_t value ) ;

## 2.9. Input/Output (IO)

The IO module consists of two separate, yet complementary parts: on the one hand, a systematic way of defining actions that take place when IO registers are accessed, and on the other the avr_io_t infrastructure, which provides unified access to module IRQs, reset and deallocation callbacks, and a Input/Output Control (IOCTL) system.

### 2.9.1. Input/Output (IO) Register Callbacks

We will examine the IO register callback system first. Whenever the simavr core reads or writes an IO register during instruction processing (see section 2.4), it first checks if a callback exists for that address. Assuming it does, a write access will result in a call to the write callback instead of setting avr-> data directly:

static inline void _avr_set_r ( avr_t * avr , uint8_t r , uint8_t v )
{
/* [...] */
uint8_t io = AVR_DATA_TO_IO ( r) ;
if ( avr - > io [ io ]. w . c )
avr - > io [ io ]. w. c ( avr , r , v , avr - > io [ io ]. w . param ) ;
else
avr - > data [ r ] = v ;
if ( avr - > io [ io ]. irq ) {
avr_raise_irq ( avr - > io [ io ]. irq +
AVR_IOMEM_IRQ_ALL , v ) ;
for (int i = 0; i < 8; i ++)
avr_raise_irq ( avr - > io [ io ]. irq + i , ( v >> i ) & 1) ;

2.9 Input/Output (IO) | 2 simavr Internals

}
/* [...] */
}

This snippet contains several interesting bits; first of all, we are reminded that IO addresses are offset by 0x20 (these are added by AVR_DATA_TO_IO). Next up, we see that write callbacks need to set the avr->data value themselves if necessary. Notice also that a custom parameter is passed into the callback, like most other callback systems in simavr . Finally, the associated IOMEM IRQs are raised; both bitwise and the byte IRQ AVR_IOMEM_IRQ_ALL.
Read accesses are very similar, except that (somewhat counter-intuitively), the value returned by the callback is automatically written to avr->data. Access callbacks plus associated IOMEM IRQs are stored in the avr->io array. MAX_IOs is currently set to 279, enough to handle all used IO registers on AVRs like the atmega1280, which go up to an address of 0x136⁹

struct {
struct avr_irq_t * irq ;
struct {
void * param ;
avr_io_read_t c ;
} r ;
struct {
void * param ;
avr_io_write_t c;
} w ;
} io [ MAX_IOs ];

Callbacks are registered using the function duo of avr_register_io_write and avr_register_io_read. IRQs are created on-demand whenever the avr_iomem_getirq function is called.
The included simavr modules (implemented in files beginning with the avr_ prefix) provide many practical examples of IO callback usage; for example, the avr_timer module uses IO callbacks to start the timer when a clock source is enabled through the timer registers.

### 2.9.2. The avr_io_t Module

The avr_io_t infrastructure provides additional functionality to modules, including reset and deallocation callbacks, central IRQ handling, and a IOCTL function. The full struct reference is provided here for reference:

9 279 = 0x136 − 0x20 + 0x01

2.9 Input/Output (IO) | 2 simavr Internals

typedef struct avr_io_t {
struct avr_io_t * | next ;
avr_t * | avr ;
const char * | kind ;

const char ** irq_names ;

uint32_t | irq_ioctl_get ;
int | irq_count ;
struct avr_irq_t * | irq ;

void (* reset ) ( struct avr_io_t * io ) ;
int (* ioctl ) ( struct avr_io_t * io , uint32_t ctl , void * io_param ) ;
void (* dealloc ) ( struct avr_io_t * io ) ;
} avr_io_t ;

Initialization in the avr_ioport Module

For a typical way of initializing an avr_io_t struct, let’s look at the avr_ioport module.

static const char * irq_names [ IOPORT_IRQ_COUNT ] = {
[ IOPORT_IRQ_PIN0 ] = " = pin0 " ,
[ IOPORT_IRQ_PIN1 ] = " = pin1 " ,
/* [...] */
[ IOPORT_IRQ_PIN7 ] = " = pin7 " ,
[ IOPORT_IRQ_PIN_ALL ] = " = all " ,
[ IOPORT_IRQ_DIRECTION_ALL ] = " > ddr " , };
static | avr_io_t | _io = {
. kind = " port " ,
. reset = avr_ioport_reset , . ioctl = avr_ioport_ioctl , . irq_names = irq_names ,
};

Once again, struct set initialization is used to partially configure a module. Passed in are the reset and IOCTL handlers, a module name (for debugging purposes), and a list of IRQ names. The deallocation handler is not used by the avr_ioport module.

2.9 Input/Output (IO) | 2 simavr Internals

void avr_ioport_init ( avr_t * avr , avr_ioport_t * p ) {
p - > io = _io ;

avr_register_io ( avr , &p - > io ) ;
avr_register_vector ( avr , &p - > pcint ) ;
avr_io_setirqs (& p - > io , AVR_IOCTL_IOPORT_GETIRQ (p - > name ) , IOPORT_IRQ_COUNT , NULL );

avr_register_io_write ( avr , p - > r_port , avr_ioport_write , p ) ;
avr_register_io_read ( avr , p - > r_pin , avr_ioport_read , p );
avr_register_io_write ( avr , p - > r_pin , avr_ioport_pin_write , p ) ; avr_register_io_write ( avr , p - > r_ddr , avr_ioport_ddr_write , p ) ;
}

Moving on to avr_ioport_init; the private, partially initialized avr_io_t is copied to the avr_ioport_t. io is the first member of the module struct to facilitate easy simple conversion between avr_io_t and avr_ioport_t pointers (this is used in the IOCTL function).

avr_register_io adds the IO module to the linked list stored in the main avr_t instance, which is iterated at AVR reset and deallocation events; it is also used by the IOCTL and to retrieve IRQs.

avr_io_setirqs is then called to create the IOPORT IRQs. The ID generated by AVR_IOCTL_IOPORT_GETIRQ is stored for subsequent use during IRQ retrieval.

The remaining functions called by avr_ioport_init have been left in to convey a complete picture of avr_ioport initialization. avr_register_vector registers the external interrupt vector, and the avr_register_io_* functions create access handlers on IO registers as discussed in section 2.9.1.

Implementation Overview

IOCTLs provide a way to trigger arbitrary functionality¹⁰ in modules. Whenever a IOCTL is triggered by calling avr_ioctl, the IOCTL handler of all

10 For example, the avr_ioport module uses the IOCTL system to allow extracting the state of a particular port’s PORT, PIN, and DDR registers; avr_eeprom allows getting and setting memory locations.

2.10 Value Change Dump (VCD) Files | 2 simavr Internals

modules registered in the avr->io_port linked list is called in sequence until one responds to that particular command by returning a value other than -1. This is then returned to the caller.

The reset handler is called whenever avr_reset is called, allowing the module to do react appropriately. In qsimavr , a major reason for registering as a avr_io_t module was to recreate cycle timers and restart VCD traces.

If a module allocates resources, these can be freed during the deallocation handler.

Finally, avr_io_getirq lets a module “publish” its IRQs for use by other modules or applications built on top of simavr . This function is used whenever a qsimavr component is connected to simavr modules:

avr_connect_irq ( avr_io_getirq ( avr , AVR_IOCTL_IOPORT_GETIRQ ( PORT ) , PIN ) , irq + IRQ_TEMP_DQ ) ;

## 2.10. Value Change Dump (VCD) Files

VCD is a simple file format for dumps of signal changes over time. Each file consists of a header containing general information (most importantly, the used timescale which is always 1ns in simavr dumps), variable definitions (containing the name and size of each tracked signal), and finally the value changes themselves. The following example contains the header section, variable definitions, and initial value changes of a three signal VCD file generated by simavr :

$timescale 1ns $end
$scope module logic $end
$var wire 1 ! <temp.data $end $var wire 1 " >temp.data $end $var wire 1 # <temp.ddr $end $upscope $end
$enddefinitions $end
$dumpvars
0!
0"
0#
$end
#36072750

0!
#36072875

2.11 Core Definitions | 2 simavr Internals

1"
1!
1#
[...]

VCD files can be displayed and analyzed graphically by wave viewers. On Linux, gtkwave is well suited for this task (see Figure 2.1).

Figure 2.1.: GTKWave

The simavr VCD implementation uses a combination of cycle timers and IRQs to track signal¹¹ changes. After initializing an avr_vcd_t with avr_vcd_init, tracked signals are configured by calling avr_vcd_add_signal . This connects an internal IRQ¹² to the tracked signal, which has _avr_vcd_notify registered as a callback function. The latter is called whenever a tracked signal changes, and registers the updated value, the current cycle, and the source IRQ in its log.

| Accumulated log data is flushed periodically by a cycle timer, the period
of which is specified on avr_vcd_t initialization. When a large amount is produced on the tracked signals, it may be necessary to decrease the used period to avoid log overflows.
| Tracking can be started and stopped at any time during program execution
by calling avr_vcd_start and avr_vcd_stop. As explained in section 2.3.2, this can even be triggered from the firmware itself.

## 2.11. Core Definitions

The actual core definitions used by simavr are located in the simavr/cores subdirectory of the source tree. These definitions rely on avr-libc headers to specify the internal structure of an MCU needed for simulation.

| The core and all internal components (such as timers, Universal Asyn-
chronous Receiver/Transmitters (UARTs), IO ports, ADCs, Serial Peripheral Interfaces (SPIs), etc . . . ) are defined in an internal struct using struct

11 In simavr , each tracked signal is actually an IRQ.
12 Limited to 32 connections.

2.11 Core Definitions | 2 simavr Internals

set initialization for a terse representation. The avr_t initialization of the atmega1280 therefore clocks in at only a couple of lines:

. core = {
. mmcu = " atmega1280 " ,
DEFAULT_CORE (4) ,

. init = m1280_init ,
. reset = m1280_reset ,

. rampz = RAMPZ ,
} ,

DEFAULT_CORE¹³ initializes basic parameters included in avr-libc headers for every MCU such as RAMEND, FLASHEND, etc . . . ). The init and reset members point to callbacks which are used to (obviously) initialize and reset the MCU.

Internal components are connected to the avr_t core in the init function:

void m1280_init ( struct avr_t * avr )
{
struct mcu_t * mcu = ( struct mcu_t *) avr ;

avr_eeprom_init ( avr , & mcu - > eeprom ) ; avr_flash_init ( avr , & mcu - > selfprog ) ; avr_extint_init ( avr , & mcu - > extint ) ; avr_watchdog_init ( avr , & mcu - > watchdog ) ; avr_ioport_init ( avr , & mcu - > porta );

/* [...] */
}

A short excerpt of atmega1280’s TIMER0 initialization should throw some light on how components are configured. Notice how all register and bit locations rely on avr-libc definitions:

. timer0 = {
. name = ’0 ’ ,
. wgm = { AVR_IO_REGBIT ( TCCR0A , WGM00 ) , AVR_IO_REGBIT ( TCCR0A , WGM01 ) , AVR_IO_REGBIT ( TCCR0B , WGM02 ) } ,
. wgm_op = {
[0] = AVR_TIMER_WGM_NORMAL8 () ,

13 The argument specifies the vector size.

2.11 Core Definitions | 2 simavr Internals
[2] = AVR_TIMER_WGM_CTC () ,
[3] = AVR_TIMER_WGM_FASTPWM8 () ,
[7] = AVR_TIMER_WGM_OCPWM () ,
} ,
. cs = { AVR_IO_REGBIT ( TCCR0B , CS00 ) , AVR_IO_REGBIT ( TCCR0B , CS01 ) , AVR_IO_REGBIT ( TCCR0B , CS02 ) } , . cs_div = { 0 , 0 , 3 /* 8 */ , 6 /* 64 */ , 8 /* 256 */ , 10 /* 1024 */ } ,

. r_tcnt = TCNT0 ,

. overflow = {
. enable = AVR_IO_REGBIT ( TIMSK0 , TOIE0 ) , . raised = AVR_IO_REGBIT ( TIFR0 , TOV0 ) , . vector = TIMER0_OVF_vect ,
} ,
/* ... */
}

Adding a new MCU definition is a simple matter of creating a new sim_*.c file in simavr/cores and defining all included components with the help of avr-libc and a datasheet.

This concludes our tour of the simavr core modules. You should now have a good idea of how simavr internals work together and complement each other to create an AVR simulation which is accurate, reliable, yet simple, efficient, and easy to extend. For an example of all of these concepts in practice, take a look at the modules included with simavr . A good example is the avr_eeprom module, which uses a combination of interrupts, an avr_io_t module, and IO access callbacks to achieve the desired functionality.

# A. Setup Guide

This section provides instructions on how to retrieve, compile and install simavr on the GNU/Linux operating system.

## A.1. simavr

### A.1.1. Getting the source code

The official home of simavr is https://github.com/buserror-uk/simavr. Stable releases are published as git repository tags (direct downloads are available at https://github.com/buserror-uk/simavr/tags). To clone a local copy of the repository, run

git clone git://github.com/buserror-uk/simavr.git

### A.1.2. Software Dependencies

elfutils is the only hard dependency at run-time. The name of this package may differ from distro to distro. For example, in Ubuntu the required package is called libelf-dev.
At compile-time, simavr additionally requires avr-libc to complete its builtin AVR core definitions. It is assumed that further standard utilities (git, gcc or clang, make, etc . . . ) are already present.

simavr has been tested with the following software versions:

- Arch Linux x86 64 and i686
- elfutils 0.154
- avr-libc 1.8.0
- gcc 4.7.1
- make 3.82

Furthermore, the board usb example depends on libusb vhci and vhci hcd. For further details, see examples/board usb/README. Note however that these are not required for a fully working simavr build.

A.1 simavr | A Setup Guide

### A.1.3. Compilation and Installation

simavr ’s build system relies on standard makefiles. The simplest compilation boils down to the usual

make
make install

As usual, there are several variables to allow configuration of the build procedure. The most important ones are described in the following section:

- AVR ROOT

The path to the system’s avr-libc installation.

While the default value should be correct for many systems, it may need to be set manually if the message ’WARNING . . . did not compile, check your avr-gcc toolchain’ appears during the build. For example, if iomxx0 1.h is located at /usr/avr/include/avr/iomxx0 1.h, AVR ROOT must be set to /usr/avr.

- CFLAGS

The standard compiler flags variable.
It may be useful to modify CFLAGS for easier debugging (in which case optimizations should be disabled and debugging information enabled: -O0 -g). Additionally adding -DCONFIG SIMAVR TRACE=1 enables extra verbose output and extended execution tracing.

These variables may be set either directly in Makefile.common, or alternatively can be passed to the make invocation (make AVR ROOT=/usr/avr DESTDIR=/usr install).

Installation is managed through the usual

make install

The DESTDIR variable can be used in association with the PREFIX variable to create a simavr package. DESTDIR=/dest/dir PREFIX=/usr installs to /dest/dir but keeps the package configured to the standard prefix (/usr).

For development, we built and installed simavr with the following procedure:

make clean
make AVR_ROOT=/usr/avr CFLAGS="-O0 -Wall -Wextra -g -fPIC \ -std=gnu99 -Wno-sign-compare -Wno-unused-parameter"
make DESTDIR="/usr" install

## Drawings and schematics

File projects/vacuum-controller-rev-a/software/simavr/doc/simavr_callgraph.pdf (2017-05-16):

### sim_cmds

### sim_cycle_timers

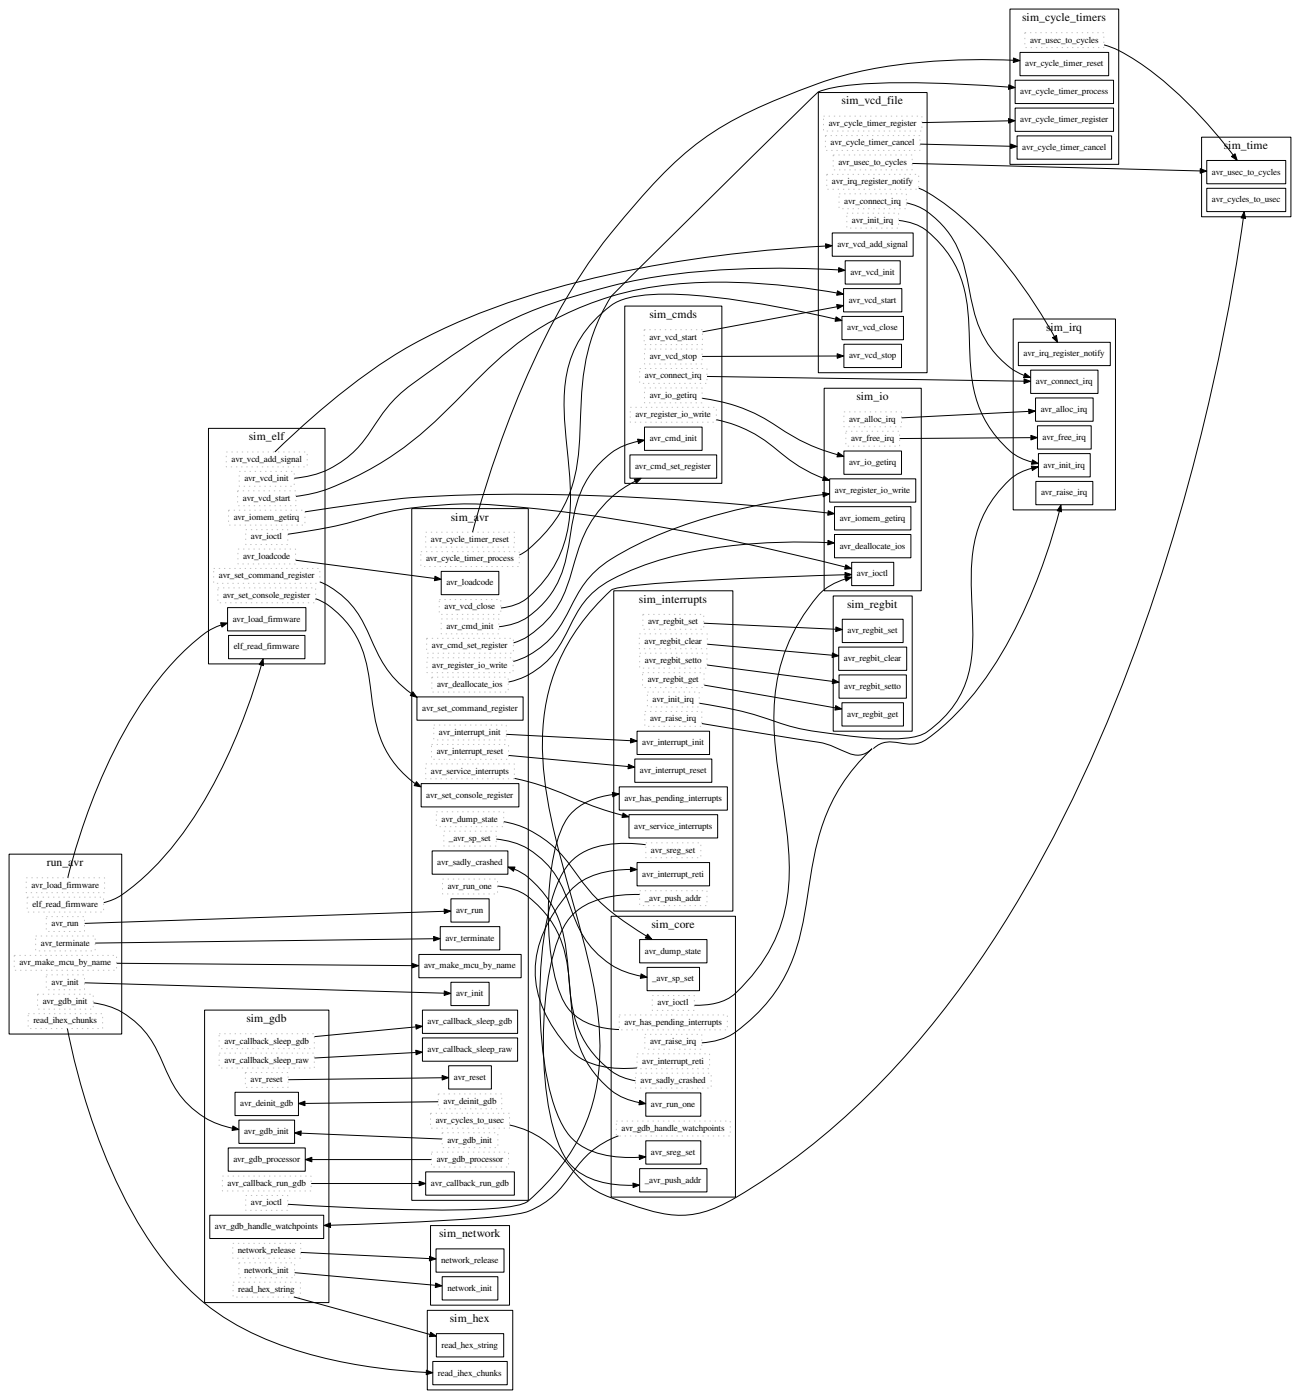
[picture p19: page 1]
sim_avr; sim_core; sim_elf; sim_gdb; sim_interrupts; sim_io; sim_vcd_file; run_avr; sim_irq; sim_time; sim_regbit; sim_hex; sim_network; avr_cmd_init; avr_interrupt_init; avr_deinit_gdb avr_deinit_gdb; avr_vcd_close; avr_deallocate_ios; _avr_sp_set; avr_interrupt_reset; avr_cycle_timer_reset; avr_gdb_init; avr_cmd_set_register; avr_register_io_write; avr_cycles_to_usec; avr_gdb_processor; avr_run_one; avr_dump_state; avr_cycle_timer_process; avr_service_interrupts; avr_callback_run_gdb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

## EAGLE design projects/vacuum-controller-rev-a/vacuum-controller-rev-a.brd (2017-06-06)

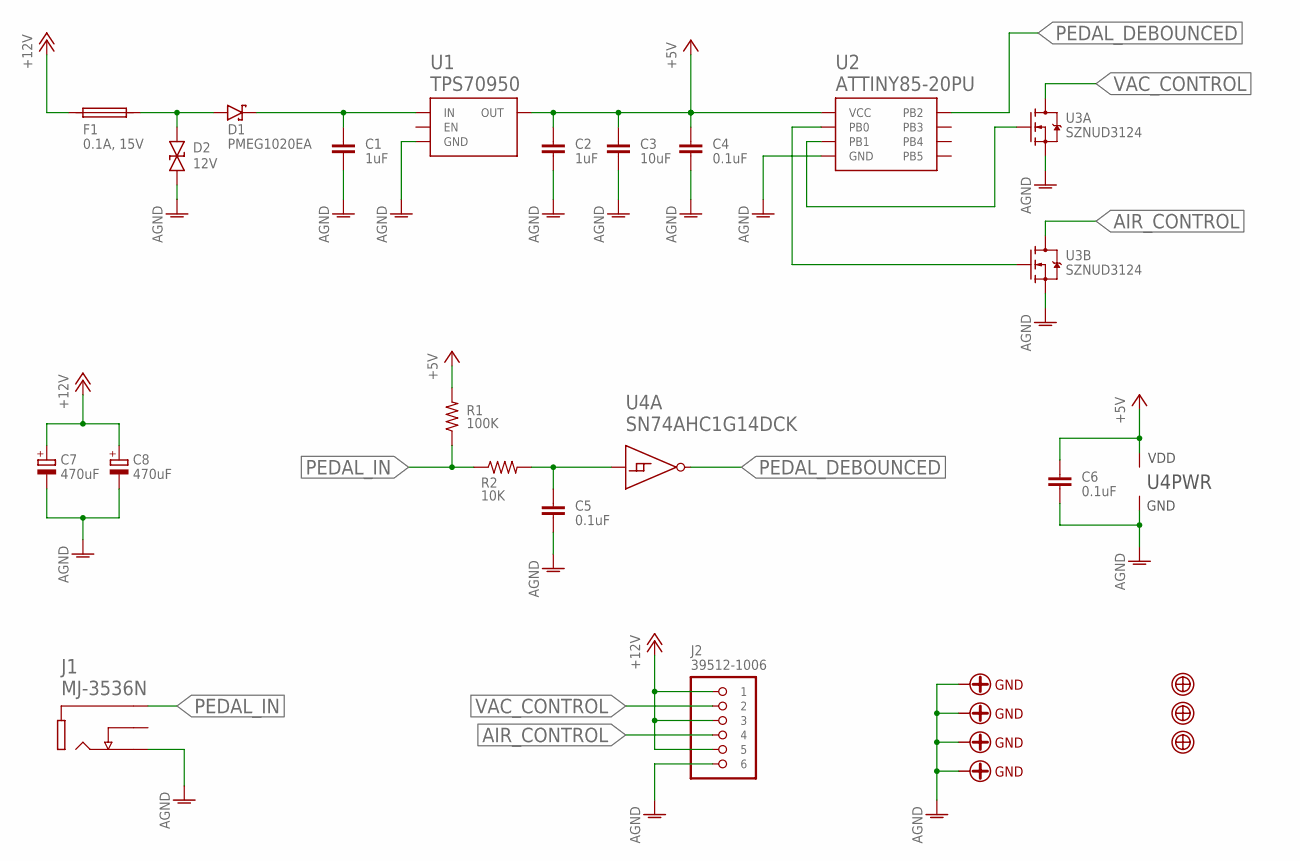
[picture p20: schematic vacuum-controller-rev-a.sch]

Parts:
C1, C2: 1uF; C0603
C3: 10uF; C0805
C4, C5, C6: 0.1uF; C0402
C7, C8: 470uF; RADIAL-D8-P3.5-PD0.5
D1: PMEG1020EA; SOD323-R
D2: 12V; SMA
F1: 0.1A, 15V; C0805
J1: MJ-3536N
J2: 39512-1006
R1: 100K; R0402
R2: 10K; R0402
U1: TPS70950; R-PDSO-G5-DBV
U2: ATTINY85-20PU; PDIP-8
U3: SZNUD3124; SOT-457
U4: SN74AHC1G14DCK; R-PDSO-G5-DCK
U$1, U$2, U$3, U$4: SCREW-THRU-GND-#4
U$5, U$6, U$7: FIDUCIAL-1MM; FIDUCIAL_1MM

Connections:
+5V: C2.1, C3.1, C4.1, C6.1, R1.2, U1.5 (OUT), U2.P$8 (VCC), U4.5 (VDD)
+12V: C7.+, C8.+, F1.1, J2.P$1 (1), J2.P$3 (3), J2.P$5 (5)
AGND: C1.2, C2.2, C3.2, C4.2, C5.2, C6.2, C7.-, C8.-, D2.A, J1.P$2, J2.P$6 (6), U1.2 (GND), U2.P$4 (GND), U3.1 (S), U3.4 (S), U4.3 (GND), U$1.P$1, U$1.P$2, U$1.P$3, U$1.P$4, U$1.P$5, U$1.P$6, U$1.P$7, U$1.P$8, U$1.P$9, U$2.P$1, U$2.P$2, U$2.P$3, U$2.P$4, U$2.P$5, U$2.P$6, U$2.P$7, U$2.P$8, U$2.P$9, U$3.P$1, U$3.P$2, U$3.P$3, U$3.P$4, U$3.P$5, U$3.P$6, U$3.P$7, U$3.P$8, U$3.P$9, U$4.P$1, U$4.P$2, U$4.P$3, U$4.P$4, U$4.P$5, U$4.P$6, U$4.P$7, U$4.P$8, U$4.P$9
AIR_CONTROL: J2.P$4 (4), U3.3 (D)
unnamed: C1.1, D1.C, U1.1 (IN)
unnamed: D1.A, D2.C, F1.2
unnamed: C5.1, R2.2, U4.2 (A)
unnamed: U2.P$6 (PB1), U3.2 (G)
unnamed: U2.P$5 (PB0), U3.5 (G)
PEDAL_DEBOUNCED: U2.P$7 (PB2), U4.4 (Y)
PEDAL_IN: J1.P$1, R1.1, R2.1
VAC_CONTROL: J2.P$2 (2), U3.6 (D)

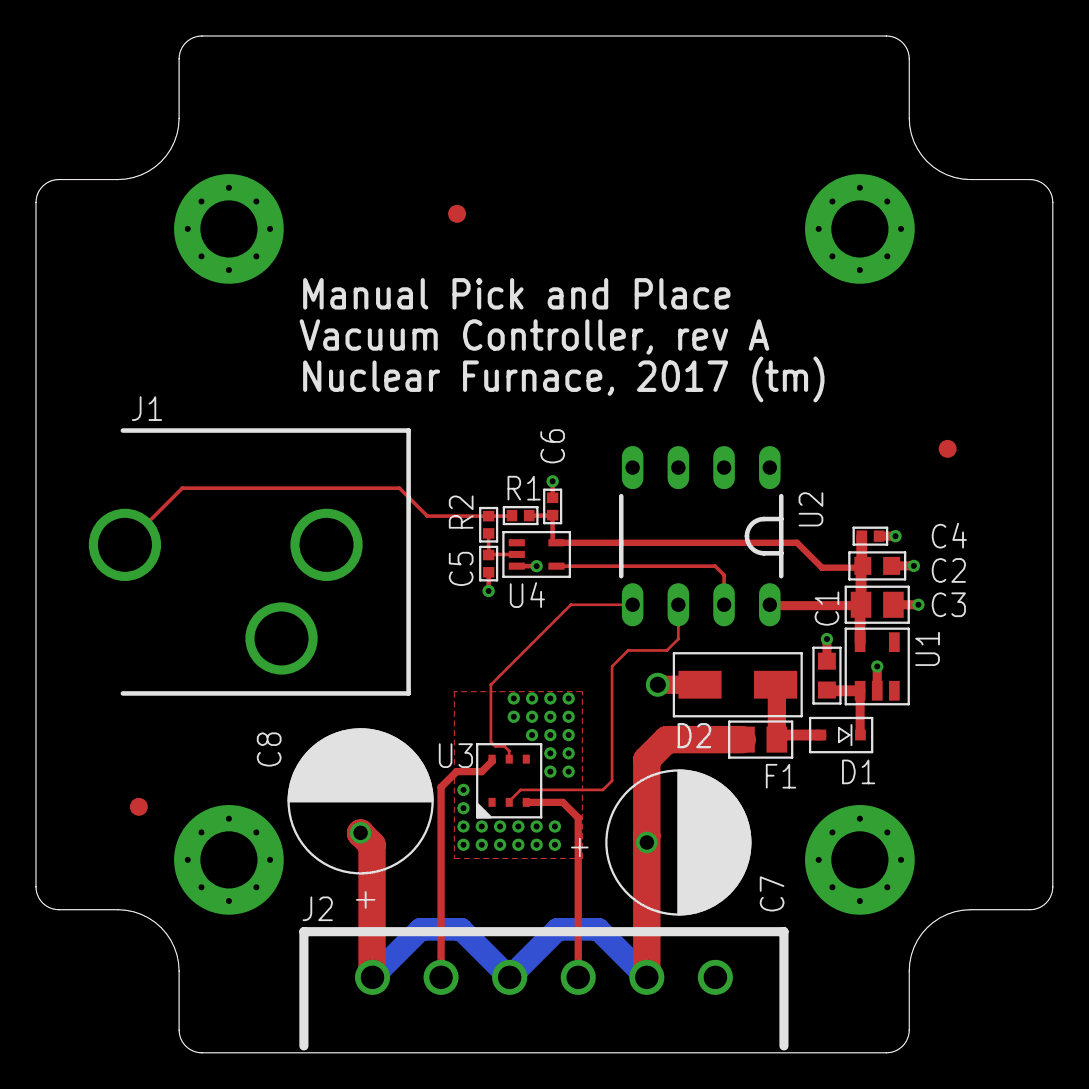
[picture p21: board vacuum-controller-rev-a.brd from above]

Board: 2 copper layers, 56.5 x 56.5 mm, 26 parts (0 on the bottom side), 12 nets.

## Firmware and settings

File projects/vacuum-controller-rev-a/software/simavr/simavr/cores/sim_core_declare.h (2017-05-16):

/*
	sim_core_declare.h

	Copyright 2008, 2009 Michel Pollet <buserror@gmail.com>

 	This file is part of simavr.

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
	You should have received a copy of the GNU General Public License
	along with simavr.  If not, see <http://www.gnu.org/licenses/>.
 */
#ifndef __SIM_CORE_DECLARE_H__
#define __SIM_CORE_DECLARE_H__

/* we have to declare this, as none of the distro but debian has a modern
 * toolchain and avr-libc. This affects a lot of names, like MCUSR etc
 */
#define __AVR_LIBC_DEPRECATED_ENABLE__

/*
 * The macros "fake" the ones in the real avrlib
 */
#define _SFR_IO8(v) ((v)+32)
#define _SFR_IO16(v) ((v)+32)
#define _SFR_MEM8(v) (v)
#define _BV(v) (v)
#define _VECTOR(v) (v)

/*
 * This declares a typical AVR core, using constants what appears
 * to be in every io*.h file...
 */
#if FUSE_MEMORY_SIZE == 6
# ifndef FUSE0_DEFAULT
#  define FUSE0_DEFAULT 0xFF
# endif
# ifndef FUSE1_DEFAULT
#  define FUSE1_DEFAULT 0xFF
# endif
# ifndef FUSE2_DEFAULT
#  define FUSE2_DEFAULT 0xFF
# endif
# ifndef FUSE3_DEFAULT
#  define FUSE3_DEFAULT 0xFF
# endif
# ifndef FUSE4_DEFAULT
#  define FUSE4_DEFAULT 0xFF
# endif
# ifndef FUSE5_DEFAULT
#  define FUSE5_DEFAULT 0xFF
# endif

# define _FUSE_HELPER { FUSE1_DEFAULT, FUSE1_DEFAULT, FUSE2_DEFAULT, \
	FUSE3_DEFAULT, FUSE4_DEFAULT, FUSE5_DEFAULT }
#elif FUSE_MEMORY_SIZE == 3
# define _FUSE_HELPER { LFUSE_DEFAULT, HFUSE_DEFAULT, EFUSE_DEFAULT }
#elif FUSE_MEMORY_SIZE == 2
# define _FUSE_HELPER { LFUSE_DEFAULT, HFUSE_DEFAULT }
#elif FUSE_MEMORY_SIZE == 1
# define _FUSE_HELPER { FUSE_DEFAULT }
#else
# define _FUSE_HELPER { 0 }
#endif

#ifdef MCUSR
# define MCU_STATUS_REG MCUSR
#else
# define MCU_STATUS_REG MCUCSR
#endif

#ifdef SIGNATURE_0
#define DEFAULT_CORE(_vector_size) \
	.ramend = RAMEND, \
	.flashend = FLASHEND, \
	.e2end = E2END, \
	.vector_size = _vector_size, \
	.fuse = _FUSE_HELPER, \
	.signature = { SIGNATURE_0,SIGNATURE_1,SIGNATURE_2 }, \
	.lockbits = 0xFF, \
	.reset_flags = {\
		.porf = AVR_IO_REGBIT(MCU_STATUS_REG, PORF),\
		.extrf = AVR_IO_REGBIT(MCU_STATUS_REG, EXTRF),\
		.borf = AVR_IO_REGBIT(MCU_STATUS_REG, BORF),\
		.wdrf = AVR_IO_REGBIT(MCU_STATUS_REG, WDRF)\
	}
#else
// Disable signature when using an old avr toolchain
#define DEFAULT_CORE(_vector_size) \
	.ramend = RAMEND, \
	.flashend = FLASHEND, \
	.e2end = E2END, \
	.vector_size = _vector_size
#endif
#endif /* __SIM_CORE_DECLARE_H__ */

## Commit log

2017-04-14 Initial commit!
    Most of the pick and place is roughly put together. The biggest things
    that remain:
    - tweaking dimensions of machined parts as pieces arrive and are test
    fit
    - adding fasteners (mates only at the moment)
    - adding proper costing (since we have it for everything minus machined
    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
    [5964K110_HARDENED PRECISION TUBULAR METRIC SHAFT.SLDPRT, 90967A165_STAINLESS STEEL EXTERNAL RETAINING RING.SLDPRT, 9657K396_STEEL COMPRESSION SPRING.SLDPRT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]
2017-04-15 Massive reorganization + adding lots of fasteners.
    I've tried to organize almost everything in functional subassemblies, as
    well as moving the actual part/assembly files into appropriate folders:
    there's a folder for custom parts I'm machining, and a folder for
    off-the-shelf (even if we modify them) parts.
    The biggest downside to the subassembly approach is that it seems to put
    the kibosh on moving components from the top-level assembly., whereas
    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
    [5964K110_HARDENED PRECISION TUBULAR METRIC SHAFT.SLDPRT, 90967A165_STAINLESS STEEL EXTERNAL RETAINING RING.SLDPRT, 91292A124_TYPE 18-8 SS SOCKET HEAD CAP SCREW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]
2017-04-17 Added proper materials and costing for all components.
    All parts now have a material and cost set. Some quirks:
    - SolidWorks doesn't have every specific material, so some of them are
    fudged (18-8 SS becomes 304, all non-10XX steel becomes alloy steel,
    etc)
    - soemn of the parts are custom, but trivial, so I gave them a "how much
    a machinist friend might charge" sort of price
    - some of the parts are actually defined as an assembly, so I split the
    cost of the actual part amongst the assembly's parts to give an accurate
    price
    Roughly speaking, the whole machine weighs right around 11.4kg (~25lbs)
    and costs about ~$500 not including the very-variable custom machined
    part pricing, and without co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
    [5964K110_HARDENED PRECISION TUBULAR METRIC SHAFT.SLDPRT, 90967A165_STAINLESS STEEL EXTERNAL RETAINING RING.SLDPRT, 91292A112_TYPE 18-8 SS SOCKET HEAD CAP SCREW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]
2017-05-03 Add the vacuum controller board to the repo.
    This board will take the foot pedal switch input and control the opening
    and closing of the vacuum valve and air valve to properly sequence the
    removal of vacuum/application of air to quickly drop a part without
    dragging it back up after positioning.
    [vacuum-controller-rev-a.brd, vacuum-controller-rev-a.sch]
2017-05-03 Small tweaks here and there; added custom designed end stops for the rails.
    [rail-end-stops.SLDDRW, rail-end-stops.SLDPRT]
2017-05-04 Starting to tweak the board layout to better suit the enclosure, as well as getting the 3D models of the connectors.
    [39512-1006.SLDPRT, LP-11F-bottom.SLDPRT, LP-11F-cover.SLDPRT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]
2017-05-04 More tweaks to the enclosure to match up to the altered board layout.
    The terminal block is now nearly flush with the outside of the case for
    full plug engagement. The mono phono jack is also nearly flush, and has
    a properly sized hole to let it get very close.
    [39512-1006.SLDPRT, LP-11F-cover.SLDPRT, MJ-3536N.sldprt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]
2017-05-11 Many changes to the schematic/board.
    - added part numbers to all components
    - added 2x470uF electrolytic caps to smooth the 12V rail during relay
    switching events
    - switched to a DIP-8 footprint for the ATtiny so we can program it in a
    cheapo programmer and not have to mess around with SOIC clips and all
    that
    [vacuum-controller-rev-a.brd, vacuum-controller-rev-a.sch]
2017-05-13 Firm up the placement bed and nozzle shaft depth.
    Firmed up the dimensions (aka the thickness) of the placement bed, and
    adjusted the circlip grooves on the nozzle shaft to properly place the
    head offset the desired amount from the bed.
    [5964K110_HARDENED PRECISION TUBULAR METRIC SHAFT.SLDPRT, 9657K124_STEEL COMPRESSION SPRING.SLDPRT, 9657K396_STEEL COMPRESSION SPRING.SLDPRT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]
2017-05-15 Add the cover panel/decal/whatever-you-want-to-call-it to the enclosure.
    Now we know what pins do what!
    [vacuum-controller.SLDASM]
2017-05-16 Add in the first cut off software for the vacuum controller.
    We have some bog-standard ANSI C targetting the AVR library to control
    the ATtiny and blip the valves and all of that.
    Right now, it's configured that it recognizes the momentary blips from
    the pedal, and does the following:
    - if the vacuum is not applied, it applies it and leaves it on
    - if the vacuum is applied, it turns it off and briefly opens the air
    valve to help provide some positive pressure to clear the line
    faster, thereby leaving the component on the board and not stuck to
    the nozzle
    We're also tightly integrated with simavr, which is a software simulator
    for running Atmel AVR code. We utilize a lot of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
2017-06-06 Some small tweaks to the grounding for the load driver.
    [vacuum-controller-rev-a.brd, vacuum-controller-rev-a.sch]
2017-06-06 Add the proper direction marking for D1.
    [vacuum-controller-rev-a.brd, vacuum-controller-rev-a.sch]

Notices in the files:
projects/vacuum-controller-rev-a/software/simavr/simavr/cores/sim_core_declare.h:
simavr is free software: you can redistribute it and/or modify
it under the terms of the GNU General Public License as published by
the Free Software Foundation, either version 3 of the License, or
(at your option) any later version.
